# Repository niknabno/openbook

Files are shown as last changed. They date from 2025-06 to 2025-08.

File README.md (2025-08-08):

# openBook
openBook is a 3d printed laptop based on a eftpos-card sized SBC and 18650s.  
Soon I plan to reinforce the lid with sheet aluminium. Perhaps laser-cut or somethin'  

I use this as my school, work, and hobby laptop however it is far from ideal for most people.  
It's thick, heavy and janky. I don't consider this a cyber_deck but it's no anyon_e either.  

It was made by me, niknabno. I made the models in openScad, as I found FreeCAD confusing. However I'm not a good programmer and the technical debt was insane.  
I made everything a literal and never got around to fixing it. PAIN. Utterly my fault, but nonetheless I'm looking at FOSS GUI CAD software now.  

Very little electronics knowledge was needed to design this, as it’s not component level. However I did still learn a lot.

# Unique features:
  * In built power supply, use an IEC C13/14 cord to charge.
  * 18650 cells only charge to ~80% (not a bug a feature, trust)
  * Turn the laptop on with a key, you'll lose it in an instant but the coolness factor is worth it.
  * Shine through backlight with custom logo/writing.
  * Upgrade easily with a new SBC.
  * 18650s make for easy battery replacement/upgrade.
  * Decent I/O compared to most modern laptops.
  * Scary looking volto-metre
  * Incandecent charging indicator (lol)
I printed this using Matte PETG filament. PLA would be OK too. Printing in black looks good, try other colours at your own risk, they can look tacky.  
I plan to use some white aswell in the future.  
Printed on a 300x300mm printer, I needed to split into multiple parts then screw and plastic-weld them together. 100% Infill is utter over kill, but that's what I used.  
Slicer: PrusaSlicer (Flatpak).

# Parts required:
  * 1kg filament. PETG, or otherwise.
  * Eftpos sized SBC. ^See footnote
  * 3-6 18650s, of any capacity.
  * Panel Mount IEC C13 socket.
  * MeanWell IRM 12-60 ST power supply.
  * 2230 or 2242 M.2 SSD (Optional for improved performance, rockPi only accepts 2230)
  * Low profile heatsink and M.2 adapter.
  * 1080p IPS panel MODEL: N140HCA-EAB
  * 30P EDP CABLE ~15CM
  * Panel mount HDMI port LINK:
  * Panel mount USB-C breakout.
  * M3 Heat Press threaded inserts LINK:
  * Lots of M3, M2.5 & M4 screws, along with nuts. LINK:
  * SPST key switch. LINK:
  * SPST Momentary nuclear launch button. LINK:
  * Super Short and thin Micro HDMI > HDMI cable. LINK:
  * Short and thin Micro HDMI > HDMI cable. LINK:
  * HDMI > EDP adapter board. However, I'm aware that a DP > EDP is better. LINK:
  * M3 hex standoffs for above board. LINK:
  * HDMI > MINI HDMI ADAPTOR. Mini hdmi cables of the right sort are hard to find. LINK:
  * Stiff (non laptop) hinges. LINK:
  * Handle, I have no specific model, so if unsure leave out.
  * 3S balanced BMS w/screw mounts. LINK:
  * 3S 18650 holder * 2. LINK:
  * Adjustable switching buck converter. LINK:
  * FPC breakout board. Link:
  * RbPi Pico
  * Panel mount voltometre if you don't want to use the SBC to monior bats. (Voltometre also looks cooler)
  * Incandecent Bulb and holder. 
  * Mean as sunnies to complete the look

# Tools required:
  * Access to an adequately sized FDM 3d printer.
  * Soldering iron.
  * Basic Phillips & flathead screwdrivers.
  * Strong double sided tape.
  * OK with computers and Linux, or willing to learn
  * Ability to pull off a matrix trench coat and sunnies.

# Arm, Is it enough?
No. I remote desktop into my x86 void-linux PC using sunshine and moonlight. Arm is overrated.  
Luckily the pi has amazing Wi-Fi.  

# Current Issues
Remeber, work in progress.
The diode used the prevent the 18650s from feeding back into the PSU and then the charging indicator will last only a few days before needing to be replaced  
It runs at like 80-100c and is very unsafe. It also causes substantual voltage drop and decreases the max capacity of the cells.  
The hinges are way too stiff... And the screen is at immense risk of shattering. Need to use aluminium to reinforce the lid.  

# Foot note:
Frankly, despite what the tech 'tubers will tell you, you're best off with an actuall rPi-5 (or 4).  
Too many people see SBCs as nothing but cheap compute. Because an old laptop just isn't sexy enough  
This means alot of SBCs that seem compatabile with the rasberry pi "standard", are actually a nightmare to intergrate.  
An x86 N100 Mini PC is NOT a Pi replacement; if it is then you must be rather dull person.  
There needs to be a middle ground between mini pc and SoM.  
The closest alt SBC I found was the RockPi 5B, but sadly a lack of wifi was too much of a head ache for me.

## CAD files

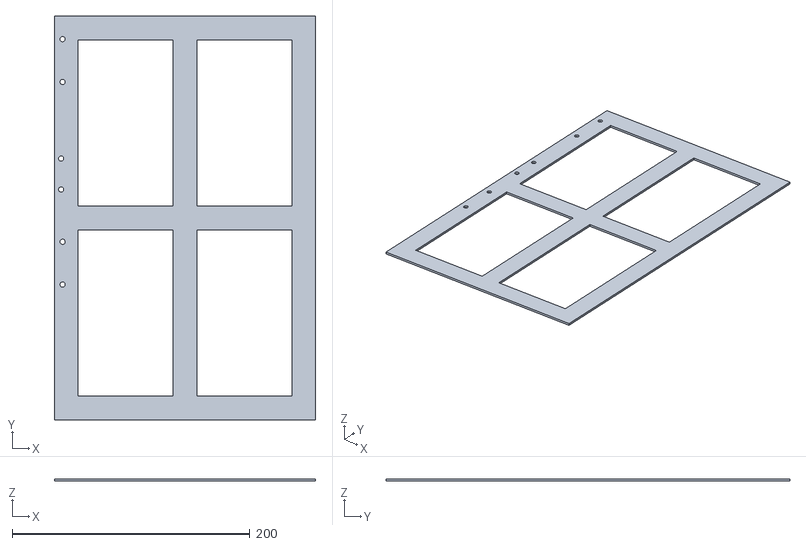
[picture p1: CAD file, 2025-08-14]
stl/aluminiumLidFrame.stl
220.0 x 340.0 x 2.00

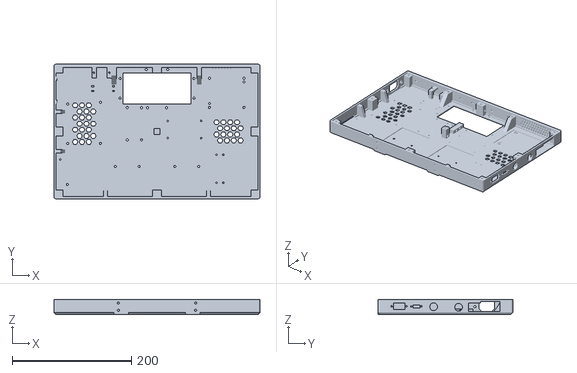
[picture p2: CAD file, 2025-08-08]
stl/base.stl
346.0 x 226.0 x 25.0

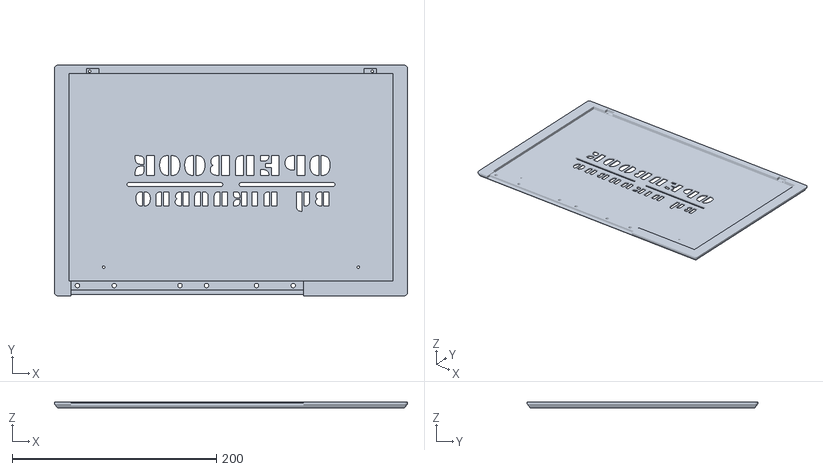
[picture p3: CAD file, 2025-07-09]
stl/lid.stl
346.0 x 226.0 x 6.00

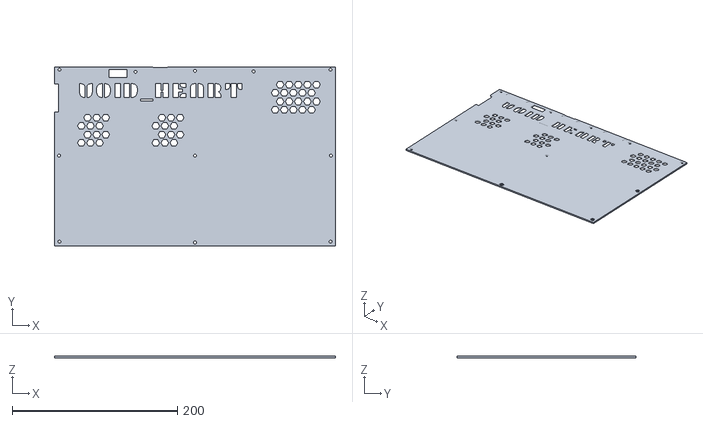
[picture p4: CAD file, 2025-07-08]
stl/top.stl
340.0 x 217.0 x 2.00

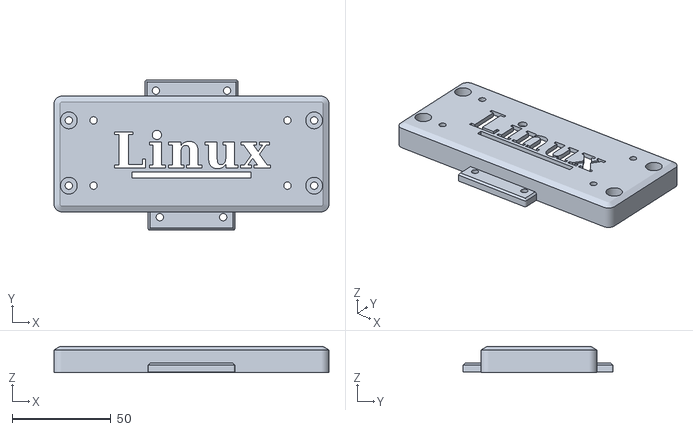
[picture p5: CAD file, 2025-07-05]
stl/psu.stl
139.0 x 76.0 x 13.2

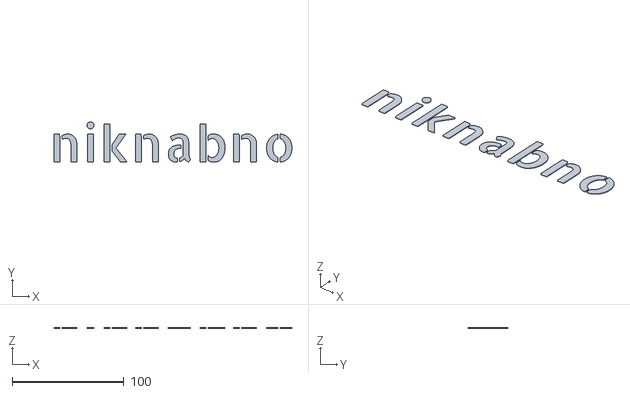
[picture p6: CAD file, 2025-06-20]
stl/logo.stl
213.2 x 36.1 x 1.00

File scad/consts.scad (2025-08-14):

l = 340;
w = 220;
h = 22;
//enable if using offical rasbPi5 cooler or using the pcb mount holes.
OFFICAL_PI_5_COOLER = false;
PI_4_ETHERNET = false; //what side the rj-45 port of the sbc is on

WALL_THICKNESS = 3;
HINGE_WALL_THICKNESS = 6; //the north wall with hinges needs to be thicker for strength
STRUCT_BRIM_THICKNESS = 5; //structural brim

BASE_THICKNESS = 3;

//the sides of the laptop, does not include wall thickness
LAPTOP_NORTH = w/2;
LAPTOP_SOUTH = -w/2;
LAPTOP_EAST = l/2;
LAPTOP_WEETBIX = -l/2;

NORTH = w/2;
SOUTH = -w/2;
EAST = l/2;
WEETBIX = -l/2;

//the zPos for if you want a component to sit flush with the bottom of the laptop.
SURFACE_MOUNT = -h/2;


//The size of the cutout for the PSU plate
PSU_HOLE_L= 114;
PSU_HOLE_W = 52;

//IEC AC connecter
IEC_W = 27.5;
IEC_H = 16.5;
IEC_HOLES_DISTANCE = 40;

IEC_Y = w/2-54.5;

IEC_CORNER_TRIANGLE_SIZE = 5; //corener triangles for aesthtics


//Square supports prevent the walls from flexing
sqrSupportW = 5;
SQR_SUPPORT_L = 12;
LARGE_SQR_SUPPORT_W = 15;

TRI_SUPPORT_W = 6.5;
TRI_SUPPORT_L = 16;
TRI_SUPPORT_ANGLE = 20;

//Cutout for pi I/O
PI_CUTOUT_W = 52.5;
PI_CUTOUT_H = 16.70;

PI_CUTOUT_ADDON_W = 19.5;
PI_CUTOUT_ADDON_H = 2.5;

//The thing that lets me screw the halves together
connecterW = 10;


BMS_X = 18;
BMS_Y = -11;


BMS_L = 56;
BMS_W = 28.7;


//BUCK_W = 20.5;
//BUCK_L = 25.5;

BUCK_W = 24;
BUCK_L = 54;

BUCK_X = -50;
BUCK_Y = -14;

picoW = 50;
picoL = 20;

picoX = 100;
picoY = -39;

//3s bat holder
BAT_W = 61;
BAT_H = 76 ;

BAT_HOLES_DISTANCE = 40;
BAT_X_OFFSET = 30;

KB_PLATE_W = 2;

sqrSupportZ = -h/3-KB_PLATE_W;
sqrSupportH = 21;

largeIntakeRadius = 4.65;
smallIntakeRadius = 0;

CORNER_SQR_S = 12; //s means size

HEATSET_INSERT_HOLE = 2.1; //the pilot hole for M3 heatpress inserts

LARGE_INTAKE_R = 4.65;

HINGE_AX = -150.5;
HINGE_BX = -50;
HINGE_CX = 20;

HINGE_THCKNESS = 0;
SMALL_HINGE_THICKNESS = 0;

BULB_HOLDER_W = 33;
BULB_HOLDER_H = 16.5;
BULB_HOLES_DIST = 25;

//for panel mount volto-metre
VOLTO_X = -110;
VOLTO_Y = LAPTOP_NORTH-16;
VOLTO_H = 6;
VOLTO_W = 10;
VOLTO_HOLE_DIST = 26; //dist between mount holes
VOLTO_L = 22;

ALUMINIUM_THICKNESS = 2;

SCREEN_W = 0;
SCREEN_H = 0;
SCREEN_THICKNESS = 0;
SCREEN_SCREW_W = 0; //the dimensions of the add ons with screw holes for the screen.
SCREEN_SCREW_H = 0;
SCREEN_EDP_X = 0; //the x of the edp connecter in the screen.

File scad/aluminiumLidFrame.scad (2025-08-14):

$fn = 90; //how many faces for circles

include<consts.scad>; //include global vars
include<modules.scad>; //include modules

h=2;//ALUMINIUM_THICKNESS;

METAL_BUFFER = 20; //width of the border and struts
METAL_CUTOUT_W = (w-METAL_BUFFER*3)/2;
METAL_CUTOUT_L = (l-METAL_BUFFER*3)/2;

difference()
{
	cube([w,l,h], center=true);

	//---start cutout for weight saving and backlight---//
	translate([LAPTOP_SOUTH+METAL_BUFFER, LAPTOP_WEETBIX+METAL_BUFFER, -h]) cube([METAL_CUTOUT_W, METAL_CUTOUT_L, h*2]);
        translate([LAPTOP_SOUTH+METAL_BUFFER, LAPTOP_EAST-METAL_BUFFER-METAL_CUTOUT_L, -h]) cube([METAL_CUTOUT_W, METAL_CUTOUT_L, h*2]);
        translate([LAPTOP_NORTH-METAL_BUFFER-METAL_CUTOUT_W, LAPTOP_WEETBIX+METAL_BUFFER, -h]) cube([METAL_CUTOUT_W, METAL_CUTOUT_L, h*2]);
        translate([LAPTOP_NORTH-METAL_BUFFER-METAL_CUTOUT_W, LAPTOP_EAST-METAL_BUFFER-METAL_CUTOUT_L, -h]) cube([METAL_CUTOUT_W, METAL_CUTOUT_L, h*2]);
	//---end cutout for weight savng and backlight---//


	//---start mount points for joining aluminium and 3d print---//
	translate([0,0,-h]) m3Hole();
	translate([w/2-METAL_BUFFER/2,0,-h]) m3Hole();
	translate([w/2-METAL_BUFFER/2,l/2-METAL_BUFFER/2,-h]) m3Hole();
	translate([w/2-METAL_BUFFER/2,-l/2+METAL_BUFFER/2,-h]) m3Hole();
        translate([0,l/2-METAL_BUFFER/2,-h]) m3Hole();
	translate([0,-l/2+METAL_BUFFER/2,-h]) m3Hole();
	//---end mount points for joining aluminium and 3d print---//

	//---start hinge mount point---//
	rotate([0,0,270])
	{
		lidHinge(HINGE_AX);
		smallLidHinge(HINGE_BX);
		lidHinge(HINGE_CX);
	}
	//---end hinge mount point---//
}

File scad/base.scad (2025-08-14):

//define how nice the curves are. Higher no. increases render times.
$fn = 90;

include<consts.scad>; //include global vars
include<modules.scad>; //include modules

//kb plate for reference. Comment out unless needed
//translate([0,0.5,h/2+2]) import("../stl/top.stl");


//start with one rounded rect, remove internal volume and mounting holes.
difference() {
	//make init rect, with 3 extra mm on all sides for walls
	minkowski(){
		cube([l, w, h], center=true);
		cylinder(WALL_THICKNESS, 0, WALL_THICKNESS);
    	}

	//cross section for reference. Comment out unless needed
	//translate([WEETBIX,SOUTH,-h/2-1]) cube([l/2,w,h]);

    	//hollow out the rect with a rim so walls are secure
    	translate([0, -2, BASE_THICKNESS])
	{
		//main hollow out
    		translate([0,1,2]) cube([l, w-(HINGE_WALL_THICKNESS-WALL_THICKNESS), h+1], center = true);
		//smaller hollow out, at lower z
		translate([0,1,0]) cube([l-STRUCT_BRIM_THICKNESS, (w-STRUCT_BRIM_THICKNESS)-(HINGE_WALL_THICKNESS-WALL_THICKNESS), h+1], center = true);
	}

    	//---start bottom intake on east side---//
    	for(a = [0 : 1 ]) {
        	for(i = [0 : 3]) {
            	translate([(i*11.5)+EAST-70, (a*20.5)-5, -20]) largeIntake();
        	}
    	}

        for(a = [0 : 1 ]) {
        	for(i = [0 : 3]) {
            	translate([(i*11.5)+EAST-64, (a*20.5)-15, -20]) largeIntake();
        	}
    	}
	//---end bottom intake on east side---//

        //---start bottom intake on west side---//
        for(a = [0 : 2 ]) {
        	for(i = [0 : 2]) {
            	translate([(i*11.5)+WEETBIX+40, (a*20.5)-7.5, -20]) rotate(0) largeIntake();
        	}
    	}

        for(a = [0 : 3 ]) {
        	for(i = [0 : 2]) {
            	translate([(i*11.5)+WEETBIX+32.5, (a*20.5)-17.5, -20]) rotate(0) largeIntake();
        	}
    	}
	//---end bottom intake on west side---//

    	//side intake. Setting res for circles to six = hexagons
    	for(a = [0 : 1 ]) {
            for(i = [0 : 13]) {
            	rotate([90, 0, 0]) translate([(i*5)+90, (a*10)-5, -w/2-10]) cylinder(25, 2.25, 2.25, $fn = 6);
    		}
             for(i = [0 : 13]) {
            	rotate([90, 0, 0]) translate([(i*5)+87, (a*10), -w/2-10]) cylinder(25, 2.25, 2.25, $fn = 6);

            }
        }

    	//Zip tie holes, to secure AC PSU wires
    	translate([-75, 67, -h]) cube([4,2,40]);
	translate([-75, 75, -h]) cube([4,2,40]);

	translate([-110, 67, -h]) cube([4,2,40]);
	translate([-110, 75, -h]) cube([4,2,40]);

	//Hinges.
	hinge(HINGE_AX);
	smallHinge(HINGE_BX);
	hinge(HINGE_CX);
	//laptopHingeA(-75, NORTH-27);
	//Let hinge be a hinge
        //translate([WEETBIX+37, NORTH-1, SURFACE_MOUNT+2.5]) cube([32.8,8, 50]);

	//switching buck converter mounting holes. On the west side of the laptop.
        /*translate([-70, -10, -20])
	{
        	translate([20, 50]) m3Hole();
        	translate([44, 50]) m3Hole();
        	translate([20, -4]) m3Hole();
        	translate([44, -4]) m3Hole();
    	}
	*/

	translate([BUCK_X, BUCK_Y, -20])
        {
                translate([0, 0]) m3Hole();
                translate([BUCK_W, 0]) m3Hole();
                translate([0, BUCK_L]) m3Hole();
                translate([BUCK_W, BUCK_L]) m3Hole();
	}


	//bms mounting holes. On east side of the laptop.
    	translate([BMS_X, BMS_Y, -12])
	{
        	m2Hole();
        	translate([BMS_L, 0, 0]) m2Hole();
        	translate([0, BMS_W, 0]) m2Hole();
		translate([BMS_L, BMS_W, 0]) m2Hole();

	}


    	translate([BMS_X, BMS_Y, -20])
	{
        	m2Hole();
    	}


    	//HDMI-EDP main board mount holes.
    	translate([-95, 49, -20]) m3Hole();
    	translate([-150, -20, -20]) m3Hole();
    	translate([-150, 46, -20]) m3Hole();
    	translate([-95, -20, -20]) m3Hole();

    	//HDMI-daughter board mount holes.
    	translate([-l/2+19.5, -w/2+21, -15]) m3Hole();
    	translate([-l/2+7.5, -w/2+63, -15]) m2Hole();

	//Pi mouning holes. M3 nuts should be used as spacers.
	//M2.5 Pi holes needs to be widened w/drill

	translate([l/2-24, w/2-3.5-17, -25]) rotate([0, 0, 90]) m3Hole();
	translate([l/2-24-58, w/2-3.5-17, -25]) rotate([0, 0, 90]) m3Hole();
	translate([l/2-24, w/2-3.5-49-17, -25]) rotate([0, 0, 90]) m3Hole();
	translate([l/2-24-58, w/2-3.5-49-17, -25]) rotate([0, 0, 90]) m3Hole();

	//allow for the pcb mount air cooler for the pi. (it sticks out below)
	if(OFFICAL_PI_5_COOLER)
	{
		translate([l/2-24, w/2-27, -25]) rotate([0, 0, 90]) m4Hole();
		translate([l/2-24-58, w/2-63, -25]) rotate([0, 0, 90]) m4Hole();
	}
	else
	{
		translate([l/2-24, w/2-27, -25]) rotate([0, 0, 90]) scale(0.85) m3Hole();
		translate([l/2-24-58, w/2-63, -25]) rotate([0, 0, 90]) scale(0.85) m3Hole();
	}


	//pi front I/O cutout
	translate([l/2-70, w/2-55.5-15.5, -6.25]) cube([85,PI_CUTOUT_W, PI_CUTOUT_H]);

    	//indent so smd components on bottom of pi can fit
    	translate([l/2-90, w/2-55.5-15.5-3, -9.75]) cube([90,PI_CUTOUT_W+6, PI_CUTOUT_H]);

    	//No spacers to fit HDMI-EDP board
    	//HDMI-EDP daughter I/O board cutout
    	translate([-l/2-10, -w/2+13, -8.5]) cube([20, 52.5, 5.5]);

	//IEC C13 cutout
	translate([WEETBIX - 25, IEC_Y+0.75, -6]) cube([90, IEC_W-1.5, IEC_H]);
    	translate([WEETBIX, IEC_Y-5, -9.5]) cube([5, IEC_W+10, IEC_H]);


	//IEC socket mountng holes
	rotate([0, 90, 0])
	{
    		translate([-2, IEC_Y+(IEC_W/2)+(IEC_HOLES_DISTANCE/2), -l/2-6])
		{
                	m3Hole();
                	translate([0,0, 2.917]) cylinder(1.25, 3, 3);
            	}
    		translate([-2, IEC_Y+(IEC_W/2)-(IEC_HOLES_DISTANCE/2), -l/2-6])
		{
                	m3Hole();
                	translate([0,0, 2.917]) cylinder(1.25, 3, 3);
            	}
   	 }


	//mounting holes for 3s 18650 holders
	for(i = [0 : 1])
	{
    		batHoles(BAT_X_OFFSET);
            	batHoles(-BAT_X_OFFSET-BAT_HOLES_DISTANCE);

            	//Inset
            	translate([-BAT_X_OFFSET-BAT_HOLES_DISTANCE/2, -w/2+51.25])
            	cube([BAT_W, BAT_H, 20], center=true);
            	translate([BAT_X_OFFSET+BAT_HOLES_DISTANCE/2, -w/2+51.25])
            	cube([BAT_W, BAT_H, 20], center=true);
       }


	//circular cutouts for switches
	rotate([0, 90, 0])
	{
    		//Key
    		translate([-2, -20, l/2-20]) cylinder(90, 6.5, 6.5);
		//rim cutout
		translate([1.5, 22, l/2-7]) cube(14, center = true);
    		//Red Button
    		translate([-1, 22, l/2-20]) cylinder(90, 6.5, 6.5);
	}

    	//USB-C cutout
    	translate([l/2-80, -w/4, 0]) cube([85, 12, 4.5]);
    	translate([l/2-1, -w/4+14.5, 2.5]) rotate([0, 90, 0]) m2Hole();
    	translate([l/2-1, -w/4-2.5, 2.5]) rotate([0, 90, 0]) m2Hole();

    	//HDMI Panel mount
    	translate([l/2-80, -w/2.5+0.5, -3]) cube([85, 19.5, 11]);
    	translate([l/2-1, -w/2.5+22.5, 2.5]) rotate([0, 90, 0]) m2Hole();
    	translate([l/2-1, -w/2.5-2.5, 2.5]) rotate([0, 90, 0]) m2Hole();

    	rotate([90, 0, 0])
    	{
        	translate([l/2-80, -w/2.5+12.5, -2.5]) m2Hole();
        	translate([l/2-80, -w/2.5-12.5, -2.5]) m2Hole();
    	}

    	//cutout for PSU indentation
	translate([0, w/2-38, -10])
	{
        	cube([PSU_HOLE_L, PSU_HOLE_W, 10], center=true);
        	//translate([PSU_HOLE_L/2-7, 0, -10]) cube([2, 99, 40]);
    	}

	//holes for the above cutout
	translate([-62, w/2-21, -20]) m3Hole();
	translate([-62, w/2-54, -20]) m3Hole();
	translate([62, w/2-21, -20]) m3Hole();
	translate([62, w/2-54, -20]) m3Hole();

	translate([-16, w/2-70, -20]) m3Hole();
    	translate([16, w/2-70, -20]) m3Hole();

	translate([18, w/2-6, -20]) m3Hole();
    	translate([-18, w/2-6, -20]) m3Hole();

	//the rim doesn't make space for nuts, so I make a cutout
	translate([18, w/2-5, -h/2+5]) cube([6,5,5], center = true);
	translate([-18, w/2-5, -h/2+5]) cube([6,5,5], center = true);

	//Holes for a door handle
	rotate([90, 0, 0])
	{
    		translate([-65, 8, 100]) m3Hole();
		translate([65, -4, 100])
		{
			translate([0,0.5,4.5])cube(10, center = true);
			m3Hole();
    		}
		translate([-65, -4, 100])
                {
                        translate([0,0.5,4.5])cube(10, center = true);
                        m3Hole();
                }
            	translate([65, 8, 100]) m3Hole();
	}

	//holes for pico
	translate([picoX, picoY, SURFACE_MOUNT-1]) m2Hole(); //m2Holder();
	translate([picoX+11.4, picoY, SURFACE_MOUNT-1]) m2Hole(); //m2Holder();
	translate([picoX, picoY-47, SURFACE_MOUNT-1]) m2Hole(); //m2Holder();
	translate([picoX+11.4, picoY-47, SURFACE_MOUNT-1]) m2Hole(); //m2Holder();
}


/*
---------------------
Below is addative.
----------------------
*/
//Clean up pi cutout

//rotate([0, 180, 0]) translate([0,0,10])import("psuPlateLarge.stl");

//Fits above rj-45 bcuz is shorter than the usb-a connecters
if(PI_4_ETHERNET)
{
	translate([EAST, w/2-38, 8]) cube([3, PI_CUTOUT_ADDON_W, PI_CUTOUT_ADDON_H]);
}
else
{
	translate([EAST, w/2-71, 8]) cube([3, PI_CUTOUT_ADDON_W, PI_CUTOUT_ADDON_H]);
}

//voltometre mount point
translate([VOLTO_X-1,VOLTO_Y,SURFACE_MOUNT+1.5])
{
	voltometreMount();
        //translate([7,0,17]) cube([22, 10, 6]);
}
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

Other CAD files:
scad/carbonPlateLid.scad
scad/fullLaptop.scad
scad/incandecentHolder.scad
scad/lid.scad
scad/modules.scad
scad/newLid.scad
scad/psu.scad
scad/top.scad
scad/topWithKB.scad

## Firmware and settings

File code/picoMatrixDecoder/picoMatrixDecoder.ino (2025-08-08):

/*
This is an adapted version of Frank Adam's keyboard matrix decoder, made to work with the rPi-pico.
*/

/* Copyright 2020 Frank Adams
   Licensed under the Apache License, Version 2.0 (the "License");
   you may not use this file except in compliance with the License.
   You may obtain a copy of the License at
       http://www.apache.org/licenses/LICENSE-2.0
   Unless required by applicable law or agreed to in writing, software
   distributed under the License is distributed on an "AS IS" BASIS,
   WITHOUT WARRANTIES OR CONDITIONS OF ANY KIND, either express or implied.
   See the License for the specific language governing permissions and
   limitations under the License.
*/
// It will determine how a laptop keyboard matrix is wired using a Teensy 3.2 on an FPC daughterboard.
// Open an editor on a computer and load or create a file that lists every key
// on the laptop keyboard that will be tested. Connect the FPC cable of the test keyboar
// to the Teensy/FPC board. Connect a USB cable from the Teensy to the computer.
// Wait a few seconds for the computer to see the Teensy as a keyboard. If numbers are reported on the screen
// before any keys are pressed, these pin numbers are shorted together and must be fixed.
// Press each key one by one on the test keyboard as listed on the editor screen. When a key
// is pressed on the test keyboard, the program detects which two pins on the FPC connector
// were connected. Those two pin numbers are sent over USB (separated by a TAB) and displayed
// on the editor. After sending the numbers, a DOWN ARROW is sent over USB to prepare for
// the next key. Once all keys on the test keyboard have been pressed, the file in
// the editor can be saved to create a row-column matrix.
//
// If your keyboard has diodes, you must pay attention to the order of the two pins that are reported by the Teensy. The code performs 
// a bottom up test first, followed by a top down test so that one of the two tests will forward bias the diode. 
// The first pin reported over USB is the cathode side and the second pin is the anode side. The diode direction must be taken into 
// account when programming the TMK or Teensyduino keyboard routine.
//
// Revision History
// Rev 1.00 - Nov 18, 2018 - Original Release
// Rev 1.1 - April 19, 2020 - Use min_pin in bottom up loop
//
//
#include <Keyboard.h>
//
//
// Load an array with the Teensy 3.2 I/O numbers that correspond to FPC pins 1 thru 34.
 int con_pin[] = {23, 0, 22, 1, 21, 2, 20, 3, 19, 4, 18, 5, 17, 6, 24, 7, 25, 8, 33, 9, 26, 10, 27, 11, 28, 12, 32, 31, 30, 29, 16, 15, 14, 13};
//
// Define maximum and minimum pin numbers that will be tested.
// max_pin is usually set to the FPC connector size. min_pin is usually set to 1. The routine will start testing at pin 1 and go up to the max pin size.
// The max and min pin values can be adjusted to exclude testing the FPC traces at the edges if they are reported as shorted. An example would be if pin 1
// and pin 34 are both grounds. They will be reported as tied together but they are not needed by the key matrix. In this case, set the 
// min_pin to 2 and the max_pin to 33.
//
int max_pin = 33; // the keyboard FPC connector pin count. If set to 34, unsolder the LED orthe code won't work
int min_pin = 1; // the first pin to be tested on the FPC connector (usually pin 1)
//
// load the key codes used in sending usb numbers, tab, and down arrow
int key_1 = KEY_F1;
int key_2 = KEY_F2;
int key_3 = KEY_F3;
int key_4 = KEY_F4;
int key_5 = KEY_F5;
int key_6 = KEY_F6;
int key_7 = KEY_F7;
int key_8 = KEY_F8;
int key_9 = KEY_F9;
int key_0 = KEY_F0;
int key_tab = KEY_TAB;
int key_down = KEY_DOWN;
//
// Function to set a pin as an input with a pullup so it's high unless grounded by a key press
void go_z(int pin)
{
  pinMode(pin, INPUT_PULLUP);
  digitalWrite(pin, HIGH);
}

// Function to set a pin as an output and drive it to a logic low (0 volts)
void go_0(int pin)
{
  pinMode(pin, OUTPUT);
  digitalWrite(pin, LOW);
}

// Function to send numbers over USB for display on an editor
void usb_num(int num)  // the numbers 0 thru 33 are sent over usb as 1 thru 34
{
  switch (num) {
    case 0:
      Keyboard.set_key1(key_1);
      Keyboard.send_now();
      break;
    case 1:
      Keyboard.set_key1(key_2);
      Keyboard.send_now();
      break;
    case 2:
      Keyboard.set_key1(key_3);
      Keyboard.send_now();
      break;
    case 3:
      Keyboard.set_key1(key_4);
      Keyboard.send_now();
      break;
    case 4:
      Keyboard.set_key1(key_5);
      Keyboard.send_now();
      break;
    case 5:
      Keyboard.set_key1(key_6);
      Keyboard.send_now();
      break;
    case 6:
      Keyboard.set_key1(key_7);
      Keyboard.send_now();
      break;
    case 7:
      Keyboard.set_key1(key_8);
      Keyboard.send_now();
      break;
    case 8:
      Keyboard.set_key1(key_9);
      Keyboard.send_now();
      break;
    case 9:
      Keyboard.set_key1(key_1);
      Keyboard.send_now();
      delay(20);
      Keyboard.set_key2(key_0);
      Keyboard.send_now();
      break;
    case 10:
      Keyboard.set_key1(key_1);
      Keyboard.send_now();
      delay(50);
      Keyboard.set_key1(0);
      Keyboard.send_now();
      delay(50);
      Keyboard.set_key2(key_1);
      Keyboard.send_now();
      break;
    case 11:
      Keyboard.set_key1(key_1);
      Keyboard.send_now();
      delay(20);
      Keyboard.set_key2(key_2);
      Keyboard.send_now();
      break;
    case 12:
      Keyboard.set_key1(key_1);
      Keyboard.send_now();
      delay(20);
      Keyboard.set_key2(key_3);
      Keyboard.send_now();
      break;
    case 13:
      Keyboard.set_key1(key_1);
      Keyboard.send_now();
      delay(20);
      Keyboard.set_key2(key_4);
      Keyboard.send_now();
      break;
    case 14:
      Keyboard.set_key1(key_1);
      Keyboard.send_now();
      delay(20);
      Keyboard.set_key2(key_5);
      Keyboard.send_now();
      break;
    case 15:
      Keyboard.set_key1(key_1);
      Keyboard.send_now();
      delay(20);
      Keyboard.set_key2(key_6);
      Keyboard.send_now();
      break;
    case 16:
      Keyboard.set_key1(key_1);
      Keyboard.send_now();
      delay(20);
      Keyboard.set_key2(key_7);
      Keyboard.send_now();
      break;
    case 17:
      Keyboard.set_key1(key_1);
      Keyboard.send_now();
      delay(20);
      Keyboard.set_key2(key_8);
      Keyboard.send_now();
      break;
    case 18:
      Keyboard.set_key1(key_1);
      Keyboard.send_now();
      delay(20);
      Keyboard.set_key2(key_9);
      Keyboard.send_now();
      break;
    case 19:
      Keyboard.set_key1(key_2);
      Keyboard.send_now();
      delay(20);
      Keyboard.set_key2(key_0);
      Keyboard.send_now();
      break;
    case 20:
      Keyboard.set_key1(key_2);
      Keyboard.send_now();
      delay(20);
      Keyboard.set_key2(key_1);
      Keyboard.send_now();
      break;
    case 21:
      Keyboard.set_key1(key_2);
      Keyboard.send_now();
      delay(50);
      Keyboard.set_key1(0);
      Keyboard.send_now();
      delay(50);
      Keyboard.set_key2(key_2);
      Keyboard.send_now();
      break;
    case 22:
      Keyboard.set_key1(key_2);
      Keyboard.send_now();
      delay(20);
      Keyboard.set_key2(key_3);
      Keyboard.send_now();
      break;
    case 23:
      Keyboard.set_key1(key_2);
      Keyboard.send_now();
      delay(20);
      Keyboard.set_key2(key_4);
      Keyboard.send_now();
      break;
    case 24:
      Keyboard.set_key1(key_2);
      Keyboard.send_now();
      delay(20);
      Keyboard.set_key2(key_5);
      Keyboard.send_now();
      break;
    case 25:
      Keyboard.set_key1(key_2);
      Keyboard.send_now();
      delay(20);
      Keyboard.set_key2(key_6);
      Keyboard.send_now();
      break;
    case 26:
      Keyboard.set_key1(key_2);
      Keyboard.send_now();
      delay(20);
      Keyboard.set_key2(key_7);
      Keyboard.send_now();
      break;
    case 27:
      Keyboard.set_key1(key_2);
      Keyboard.send_now();
      delay(20);
      Keyboard.set_key2(key_8);
      Keyboard.send_now();
      break;
    case 28:
      Keyboard.set_key1(key_2);
      Keyboard.send_now();
      delay(20);
      Keyboard.set_key2(key_9);
      Keyboard.send_now();
      break;
    case 29:
      Keyboard.set_key1(key_3);
      Keyboard.send_now();
      delay(20);
      Keyboard.set_key2(key_0);
      Keyboard.send_now();
      break;
    case 30:
      Keyboard.set_key1(key_3);
      Keyboard.send_now();
      delay(20);
      Keyboard.set_key2(key_1);
      Keyboard.send_now();
      break;
    case 31:
      Keyboard.set_key1(key_3);
      Keyboard.send_now();
      delay(20);
      Keyboard.set_key2(key_2);
      Keyboard.send_now();
      break;
    case 32:
      Keyboard.set_key1(key_3);
      Keyboard.send_now();
      delay(50);
      Keyboard.set_key1(0);
      Keyboard.send_now();
      delay(50);
      Keyboard.set_key2(key_3);
      Keyboard.send_now();
      break;
    case 33:
      Keyboard.set_key1(key_3);
      Keyboard.send_now();
      delay(20);
      Keyboard.set_key2(key_4);
      Keyboard.send_now();
      break;
  }
  delay(20);
  Keyboard.set_key1(0); // clear out the key slots
  Keyboard.set_key2(0);
  Keyboard.send_now();
  delay(20);
  Keyboard.set_key1(key_tab); // Tab over to position for next number
  Keyboard.send_now();
  delay(20);
  Keyboard.set_key1(0); // clear out the tab from the slot
  Keyboard.send_now();
  delay(20);
}

// Function to send a down arrow over usb to position for the next key
void down_arrow(void) {
  Keyboard.set_key1(key_down); // send a down arrow
  Keyboard.send_now();
  delay(20);
  Keyboard.set_key1(0); // release the down arrow
  Keyboard.send_now();
}

// --------------------------------------------------Setup-----------------------------------
void setup() {
  for (int k = 0; k < max_pin; k++) {  // loop thru all connector pins
    go_z(con_pin[k]); // set each pin as an input with a pullup
  }
  delay(15000);  // Wait for the host to connect to the Teensy as a keyboard. If 2 pins are shorted,
              // you want the host to be ready to receive the pin numbers.
}
//
// -------------------------------------------Main Loop--------------------------------------
//
void loop() {
//
// ***********Bottom up Test************
//
  for (int i=min_pin-1; i<max_pin-1; i++) {   // outer loop pin (min_pin-1 is typically = 0)
    go_0(con_pin[i]); // make the outer loop pin an output and send this pin low
    for (int j=i+1; j<max_pin; j++) {   // inner loop pin
      delayMicroseconds(10); // give time to let the signals settle out
      if (!digitalRead(con_pin[j])) {  // check for connection between inner and outer pins
        usb_num(i); // send outer loop pin number over usb
        usb_num(j); // send inner loop pin number over usb
        down_arrow(); // send a down arrow over usb
        while(!digitalRead(con_pin[j])) {  // wait until key is released
           ;                              // if 2 pins are shorted, the code will hang here
        }
      }
    }
  go_z(con_pin[i]); // return the outer loop pin to float with pullup
  }
//
// *********Top down Test***********
//
  for (int p=max_pin-1; p>min_pin-1; p--) {   // outer loop pin
    go_0(con_pin[p]); // make the outer loop pin an output and send this pin low
    for (int r=p-1; r>=min_pin-1; r--) {   // inner loop pin
      delayMicroseconds(10); // give time to let the signals settle out
      if (!digitalRead(con_pin[r])) {  // check for connection between inner and outer pins
        usb_num(p); // send outer loop pin number over usb
        usb_num(r); // send inner loop pin number over usb
        down_arrow(); // send a down arrow over usb
        while(!digitalRead(con_pin[r])) {  // wait until key is released
		;
	}
      }
    }
  go_z(con_pin[p]); // return the outer loop pin to float with pullup
  }
//
delay(25);  // overall keyboard scan rate is about 30 milliseconds
//

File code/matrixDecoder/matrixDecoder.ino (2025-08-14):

//copied/inspired by Frank Adam's keyboard matrix decoder. Made to work on the Rasbery Pi Pico
//I believe Mr. Adams has a Python equivlent of this, however I find c++ more convnient.
//Also, there is a high likley hood Mr. Adams might make one of these himself, but I don't believe
//he has at the time of writting

//1: open and focus a text editor
//2: press each key on by one
//3: this will form a matrix for your specfic keyboard

//#include "pico/stdlib.h" //standard lib
#include "tusb.h"; //tinyUSB library for USB HID

uint8_t LED_PIN = 25; //led pin on the pico

//this array contains pins on pico that correspond to FPC pins in order.
uint8_t pico_pins[] = {};

uint8_t MAX_PIN = 30; //how many pins your FPC cable has
uint8_t MIN_PIN = 1;

uint8_t key_1 = 0x1E;
uint8_t key_2 = 0x1F;
uint8_t key_3 = 0x20;
uint8_t key_4 = 0x21;
uint8_t key_5 = 0x22;
uint8_t key_6 = 0x23;
uint8_t key_7 = 0x24;
uint8_t key_8 = 0x25;
uint8_t key_9 = 0x26;
uint8_t key_0 = 0x27;
uint8_t KEY_TAB = 0x2B;
uint8_t KEY_DOWN = 0x51;

//array stores all the keycodes. Index 0 = keycode 0. Index 1 = keycode 1 - etc
uint8_t keyArr[] = {





};

//func to send a keypress
void sendKey(uint8_t keycode) {
    tud_hid_keyboard_report(0, 0, &keycode);
}

//function to set a pin as an input w/pullup so it's high unless grounded by a keypress
void setInput(uint8_t pin)
{
    _gpio_init(pin);
    gpio_set_dir(pin, GPIO_IN); //set pin as input
    gpio_pull_up(pin); //enable pull-up resistor
}

//func to set a pin as output and drive it to a logic low (0v)
void setOutput(uint8_t pin)
{

}

//func to send numbers for display on an editor
void displayNum(uint8_t num)
{
	tusb_init(); //init usb emu
        tud_task(); //tinyUSB task

	sendKey(keyArr[num]);
        sleep_ms(100); //vroom vroom
	sendKey(KEY_TAB); //tab over to the next pos for the next key
	sleep_ms(100);
}

//send down arrow to text editor with correct delays n' stuff
void downArrow(void)
{
	sendKey(KEY_DOWN);
	delay(20);
}

void setup()
{
	for (uint8_t i = 0; i < MAX_PIN; i++)
	{
		setInput(pico_pin[i]); //set each pin as input w/pullip
	}
	delay(15000); //wait for host to connect to pico as a kb.
}


//---start main loop---//
void loop()
{
	//---bottom up test---//
	for(uint8_t i = MIN_PIN-1; i<MAX_PIN-1; i++)
	{
		setOutput(picoPins[i]); //make the outer loop pin an output and set to low
		for(uint8_t j=i+1; j < MAX_PIN; j++)
		{
			delayMicroSeconds(10); //give time for signals to settle out
			if(!digitalRead(picoPins[j])) //check for connection between inner and outter pins
			{
				displayNum(i);
				displayNum(j);
				downArrow();
				while(!digitalRead(picoPins[j])) {}; //if two pins shorted the code hangs here
			}
		}

		setInput(picoPins[i]); //
	}

	//---top down test---//
}

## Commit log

2025-06-15 Add the latest WIP files.
    Currently redesigning entire laptop with better screen, SBC, battery, KB, hinge - etc.
    [lid.scad, openBookBase.scad, psuExtension.scad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]
2025-06-20 slightly cleaned up code. simplfied file name
    [base.scad]
2025-06-20 delegarted consts to a seprate file. Added svg that i might use?
    [base.scad, lid.scad, openBookBase.scad]
2025-06-20 added consts to seprate file. Added niknabno stl, fixed bottom wall thickness. Working on another screw poinht to secure topPlate.
    [base.scad, consts.scad, logo.stl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]
2025-06-21 Started moving modules to shared file. Reogranised dirs.
    [base.scad, consts.scad, lid.scad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]
2025-06-21 Added stencil font. Gave lid rounded corners. Made lid/hinge connection more secure.
    [consts.scad, lid.scad, modules.scad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]
2025-06-21 further cleaned up code. Changed psuExtension.scad to psu.scad. Fixed hole size on lid. M3 --> M4
    [consts.scad, lid.scad, modules.scad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]
2025-06-21 added full laptop mockup, added indents to prevent screw scuffing plastic when lid closed. Other tweaks.
    [base.scad, base.stl, consts.scad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]
2025-06-22 added more screw holes to top. Made finalLaptop.scad better
    [base.scad, fullLaptop.scad, top.scad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]
2025-07-04 fuckin' pro-gamer, eh? Changes to be committed: modified: scad/base.scad modified: scad/consts.scad modified: scad/fullLaptop.scad new file: scad/incandecentHolder.scad modified: scad/lid.scad modifi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
    [base.scad, base.stl, consts.scad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]
2025-07-04 Changes to be committed: modified: scad/base.scad modified: scad/consts.scad modified: scad/lid.scad modified: scad/top.scad modified: stl/lid.stl modified: stl/top.stl
    [base.scad, consts.scad, lid.scad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]
2025-07-05 Changes to be committed: modified: base.scad modified: consts.scad modified: incandecentHolder.scad modified: modules.scad modified: psu.scad modified: ../stl/base.stl modified: ../stl/psu.stl
    [base.scad, base.stl, consts.scad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]
2025-07-05 added more cutouts to rim Changes to be committed: modified: base.scad
    [base.scad]
2025-07-05 Added voltometre mount. might not fit idk. Changed front text to be more serious. To do: make sure voltometre has some tolenrence, and isnt flush, cuz is right next to hinge. Changes to be committed: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
    [base.scad, consts.scad, lid.scad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]
2025-07-05 the voltometre mount is now very cool. Changes to be committed: modified: ../README.md modified: base.scad modified: consts.scad modified: modules.scad modified: ../stl/base.stl
    [base.scad, base.stl, consts.scad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]
2025-07-08 fuck off ya nerd Changes to be committed: modified: base.scad modified: fullLaptop.scad modified: top.scad modified: ../stl/base.stl modified: ../stl/top.stl
    [base.scad, base.stl, fullLaptop.scad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]
2025-07-09 lid ay?
    [lid.scad, lid.stl, modules.scad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]
2025-07-11 change screen mount holes modified: lid.scad modified: modules.scad
    [lid.scad, modules.scad]
2025-07-11 most people kinda lame. these commit notes bad. modified: modules.scad
    [modules.scad]
2025-07-11 Changes to be committed: modified: lid.scad modified: modules.scad
    [lid.scad, modules.scad]
2025-07-11 Changes to be committed: modified: modules.scad
    [modules.scad]
2025-07-11 death to spain! Changes to be committed: modified: lid.scad modified: modules.scad
    [lid.scad, modules.scad]
2025-08-08 decided to write a new file for pico decoding instead of editing. Cleaned up scad a little. Long way to go tho... Added new scad files but haven't started filling them yet. Changes to be committed: n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
    [aluminiumLidFrame.scad, base.scad, base.stl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]
2025-08-14 Added more consts, but still more work to do on that. Added the start of a new lid design. Changes to be committed: modified: ../code/matrixDecoder/matrixDecoder.ino modified: aluminiumLidFrame.scad 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
    [aluminiumLidFrame.scad, aluminiumLidFrame.stl, base.scad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]
